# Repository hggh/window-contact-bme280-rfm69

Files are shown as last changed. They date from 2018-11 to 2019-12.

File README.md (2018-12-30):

# window-contact-rfm69

## Parts
 * Atmel 328p
 * RFM69
 * copper foil as contact
 * CR2032 battery

 ## fuse
  * disable BOD
  * internal 1Mhz

the back side of the case. the contacts are made with tiny copper foil.

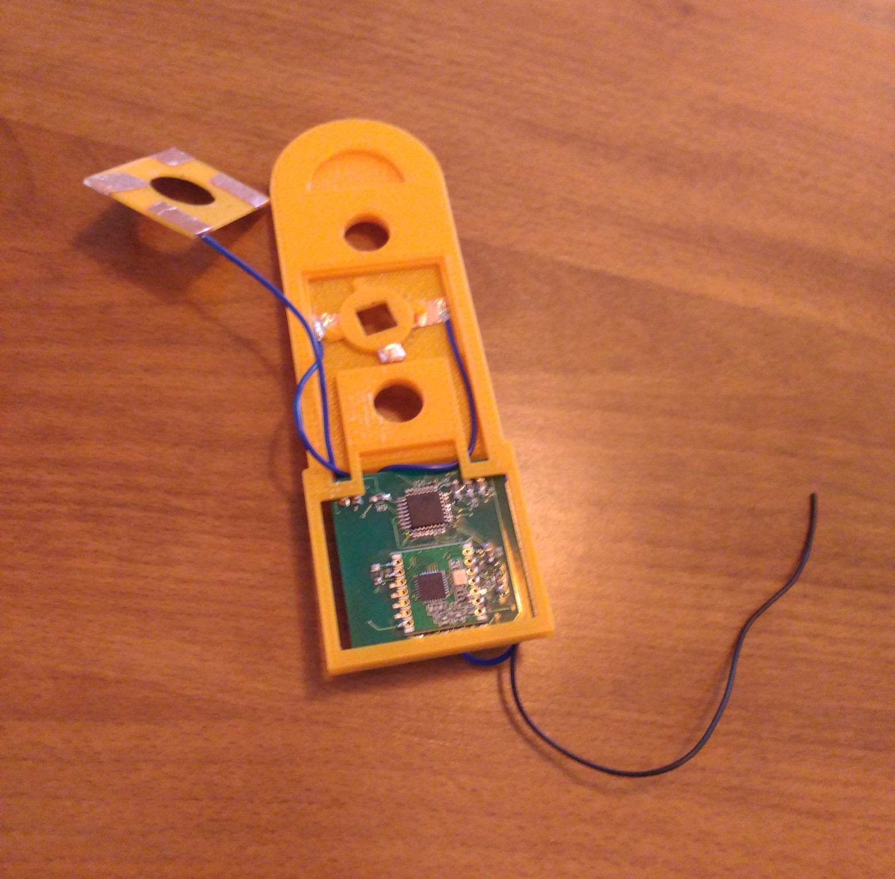
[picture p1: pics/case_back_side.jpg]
case_back


window is half opened and cover is missing to hide the pcb

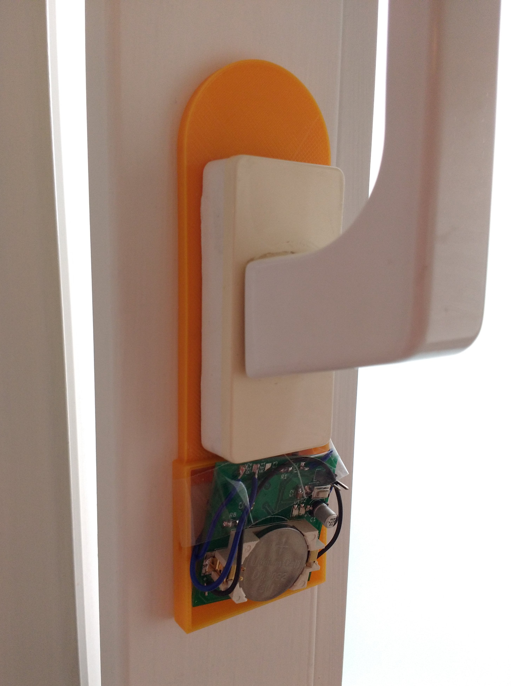
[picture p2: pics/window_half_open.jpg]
window


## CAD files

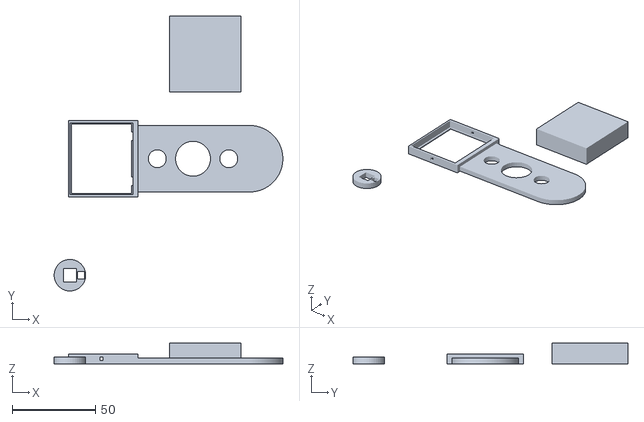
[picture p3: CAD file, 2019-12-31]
case/case-reed-contacts.stl
137.5 x 165.3 x 12.5

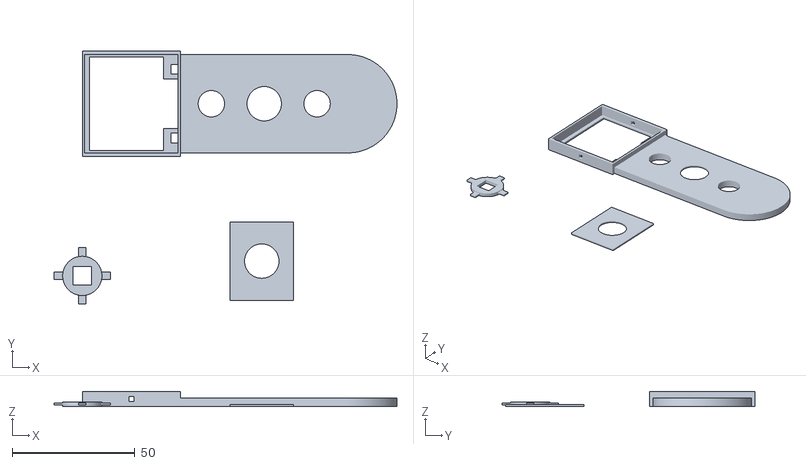
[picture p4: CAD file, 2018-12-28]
case/case.stl
139.5 x 103.0 x 6.00

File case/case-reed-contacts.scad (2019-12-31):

VIERKANT = 7.5;
BREITE = 40;
HOEHE = 68;
BOHRUNGEN = 10.75;

module inlay() {
	difference(){
		cylinder($fn=40, h=4, r=((32/2) - 6.5));
		cube([(VIERKANT + 0.5), (VIERKANT + 0.5), 10], center=true);
		translate([(((32/2)-6)- 3.3), 0, 0]) {
			cube([4, 4.5, 10], center=true);
		}
	}
}

module box() {
    difference() {
        cube([HOEHE, BREITE, 3.5]);
        // Bohrung unten
		translate([(HOEHE - ((HOEHE - 43) / 2)), (BREITE / 2), -1]) {
			cylinder($fn=40 ,h=7, r=(BOHRUNGEN / 2));
		}       
        // Bohrung oben
		translate([((HOEHE - 43) / 2), (BREITE / 2), -1]) {
			cylinder($fn=40, h=6, r=(BOHRUNGEN / 2));
		}
        // Mitte
        translate([((43/2)+((HOEHE-43)/2)),(BREITE/2),-1]) {
			cylinder($fn=40, h=10, r=10.5);
		}
        //Reed Contact
        translate([ (HOEHE-43)/2, (BREITE - 2.2 - 3), -1]) {
            cube([30, 3, 3.3]);
		}
        //Reed Contact
        translate([ (HOEHE-43)/2, 2.2, -1]) {
			cube([30, 3, 3.3]);
		}
    }
}


translate([40, 60, 0]) {
    difference() {
        union() {
            box();
            // Rundung oben
            translate([HOEHE, BREITE / 2, 0]) {
                difference() {
                    cylinder($fn=120, r=BREITE / 2 , h=3.5);
                    translate([-BREITE, - BREITE / 2,-1]) cube([BREITE, BREITE, 10]);
                    translate([0, 0, -1]) cylinder($fn=80, r=BREITE / 2.4 , h=3);
                }
            }
            translate([-41, -3, 0]) {
                difference() {
                    cube([42, 46, 6]);
                    translate([1, 1.5, 1]) {
                        cube([38, 43, 10]);
                    }
                    translate([2, 2, -1]) {
                        cube([36, 42, 5]);
                    }
                    translate([40/2 +1 , -10, 2]) {
                        rotate([0, 0, 90]) cube([60, 2, 2]);
                    }
                }
            }
        }
        translate([-4, 4, -1]) {
            cube([75, 5, 3.7]);
        }
        translate([-4, 31, -1]) {
            cube([75, 5, 3.7]);
        }
    }
    
}


translate([0, 10, 0]) {
    inlay();
}



module deckel() {
    D_BREITE = 40;
    D_HOEHE = 43;
    D_TIEFE = 11;

    union() {
        difference() {
            cube([D_BREITE + 2.8, D_HOEHE  + 2.8,  D_TIEFE + 1.5]);
            translate([1.2, 1.2, 0]) {
                cube([D_BREITE + 0.4, D_HOEHE + 0.4,  D_TIEFE]);
            }
            translate([-1, 1.5 + 1.2, 0]) {
                cube([4, 40 +0.4, 3.5]);
            }
        }
        difference() {
            translate([40/2 + 1.2 +1 , 0, 2]) {
                rotate([0, 0, 90]) cube([D_HOEHE + 2.4,, 2, 2]);
            }
            translate([1.2, 1.2 +2, 0]) {
                cube([D_BREITE, D_HOEHE-4,  D_TIEFE +1]);
            }
        }
    }
}


translate([60, 120, 0 ]) {
    deckel();
}

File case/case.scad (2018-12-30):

VIERKANT = 7.5;
BREITE = 40;
HOEHE = 68;
BOHRUNGEN = 10.75;

module box() {
    difference() {
        cube([HOEHE, BREITE, 3.5]);
        // Bohrung unten
		translate([(HOEHE - ((HOEHE - 43) / 2)), (BREITE / 2), 0]) {
			cylinder($fn=40 ,h=4, r=(BOHRUNGEN / 2));
		}
        
        // Bohrung oben
		translate([((HOEHE - 43) / 2), (BREITE / 2), 0]) {
			cylinder($fn=40, h=4, r=(BOHRUNGEN / 2));
		}
        
        translate([((43/2)+((HOEHE-43)/2)),(BREITE/2),-1]) {
			cylinder($fn=40, h=10, r=7);
		}
        
        translate([((43/2)+((HOEHE-43)/2)) - 12,(BREITE/2) - 15, 0]) {
            cube([24, 30, 2.7]);
        }
        
        translate([((43/2)+((HOEHE-43)/2)) - 13,(BREITE/2) - 16, 0]) {
            cube([26, 32, 0.8]);
        }
    }
}


translate([40, 60, 0]) {
    difference() {
        union() {
            box();
            // Rundung oben
            translate([HOEHE, BREITE / 2, 0]) {
                difference() {
                    cylinder($fn=120, r=BREITE / 2 , h=3.5);
                     translate([-BREITE, - BREITE / 2,0]) cube([BREITE, BREITE, 10]);
                    cylinder($fn=80, r=BREITE / 3.6 , h=1.5);
                }
            }
            translate([-40, -1.5, 0]) {
                difference() {
                    cube([40, 43, 6]);
                    translate([1, 1.5, 1]) {
                        cube([38, 40, 10]);
                    }
                    translate([3, 2.5, 0]) {
                        cube([30, 38, 5]);
                    }
                    translate([40/2 +1 , -10, 2]) {
                        rotate([0, 0, 90]) cube([60, 2, 2]);
                    }
                }
            }
        }
        translate([-4, 4, 0]) {
            cube([26, 4, 2.7]);
        }
        translate([-4, 32, 0]) {
            cube([26, 4, 2.7]);
        }
        translate([-10, BREITE/ 4, 0]) {
            cube([12, 20, 2]);
        }
    }
    
}


translate([60, 0, 0]) {
    difference() {
        cube([26, 32, 0.8]);
        translate([13, 16, 0 ]) {
            cylinder($fn=40, h=10, r=7, center=true);
        }
    }
}


translate([0, 10, 0]) {
    difference(){
        union() {
            cylinder($fn=40, h=1.8, r=8);
            translate([-23 /2, -1.5 , (2 - 0.8) / 2]) {
                cube([23, 3, 0.8]);
            }
            translate([+1.5, - (23 / 2) , (2 - 0.8) / 2]) {
                rotate([0, 0, 90]) cube([23, 3, 0.8]);
            }
        }
        cube([VIERKANT, VIERKANT, 10], center=true);
    }
}



module deckel() {
    D_BREITE = 40;
    D_HOEHE = 43;
    D_TIEFE = 11;

    union() {
        difference() {
            cube([D_BREITE + 2.8, D_HOEHE  + 2.8,  D_TIEFE + 1.5]);
            translate([1.2, 1.2, 0]) {
                cube([D_BREITE + 0.4, D_HOEHE + 0.4,  D_TIEFE]);
            }
            translate([-1, 1.5 + 1.2, 0]) {
                cube([4, 40 +0.4, 3.5]);
            }
        }
        difference() {
            translate([40/2 + 1.2 +1 , 0, 2]) {
                rotate([0, 0, 90]) cube([D_HOEHE + 2.4,, 2, 2]);
            }
            translate([1.2, 1.2 +2, 0]) {
                cube([D_BREITE, D_HOEHE-4,  D_TIEFE +1]);
            }
        }
    }
}


translate([60, 120, 0 ]) {
    deckel();
}

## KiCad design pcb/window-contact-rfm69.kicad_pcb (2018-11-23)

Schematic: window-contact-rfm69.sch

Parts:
BT1: CR2032
C1: 10uF; c_elec_4x5.8
C2, C3: 100nf; C_0805_HandSoldering
D1: RE2; LED_0805
D2: RE1; LED_0805
IC1: ATMEGA328P-A; TQFP-32_7x7mm_Pitch0.8mm
P1: VCC; Wire_SMD_Pad_1PIN
P2: TX/RX; Pin_Header_Straight_1x02
P3: RE1; Wire_SMD_Pad_1PIN
P4: ISP; SMD
P5: RE2; Wire_SMD_Pad_1PIN
P6: AN; Wire_SMD_Pad_1PIN
P7: RE3; Wire_SMD_Pad_1PIN
R1: 10k; R_0805_HandSoldering
R2, R3, R7, R9: 10M; R_0805_HandSoldering
R4, R5, R6: 1k; R_0805_HandSoldering
R8: 100; R_0805_HandSoldering
RF1: RFM69; RFM96
SW1: LED ON; SMD_Button

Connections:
/MISO: IC1.16 ((PCINT4/MISO)PB4), P4.1, R4.2
/MOSI: IC1.15 ((PCINT3/OC2A/MOSI)PB3), P4.4, R6.1
/SCK: IC1.17 ((PCINT5/SCK)PB5), P4.3, R5.1
/SS: IC1.14 ((PCINT2/OC1B/~SS~)PB2), RF1.7 (NSS)
GND: BT1.2 (-), C1.2, C2.2, C3.2, IC1.3 (GND), IC1.5 (GND), IC1.21 (GND), P4.6, R2.2, R3.2, R7.2, R8.1, R9.2, RF1.3 (GND), RF1.14 (GND)
unnamed: D1.1 (K), D2.1 (K), R8.2
unnamed: D1.2 (A), IC1.8 ((PCINT7/XTAL2/TOSC2)PB7)
unnamed: D2.2 (A), IC1.7 ((PCINT6/XTAL1/TOSC1)PB6)
unnamed: IC1.1 ((PCINT19/OC2B/INT1)PD3), R9.1, SW1.1
unnamed: IC1.23 ((PCINT8/ADC0)PC0), P5.1, R3.1
unnamed: IC1.24 ((PCINT9/ADC1)PC1), P3.1, R2.1
unnamed: IC1.25 ((PCINT10/ADC2)PC2), P7.1, R7.1
unnamed: IC1.29 ((PCINT14/~RESET~)PC6), P4.5, R1.2
unnamed: IC1.30 ((PCINT16/RXD)PD0), P2.1
unnamed: IC1.31 ((PCINT17/TXD)PD1), P2.2
unnamed: IC1.32 ((PCINT18/INT0)PD2), RF1.9 (DIO0)
unnamed 28: P6.1, RF1.1 (ANT); also elsewhere on the board
unnamed: R4.1, RF1.8 (MISO)
unnamed: R5.2, RF1.6 (SCK)
unnamed: R6.2, RF1.5 (MOSI)
VCC: BT1.1 (+), C1.1, C2.1, C3.1, IC1.4 (VCC), IC1.6 (VCC), IC1.18 (AVCC), P1.1, P4.2, R1.1, RF1.2 (VCC_3.3V), SW1.2

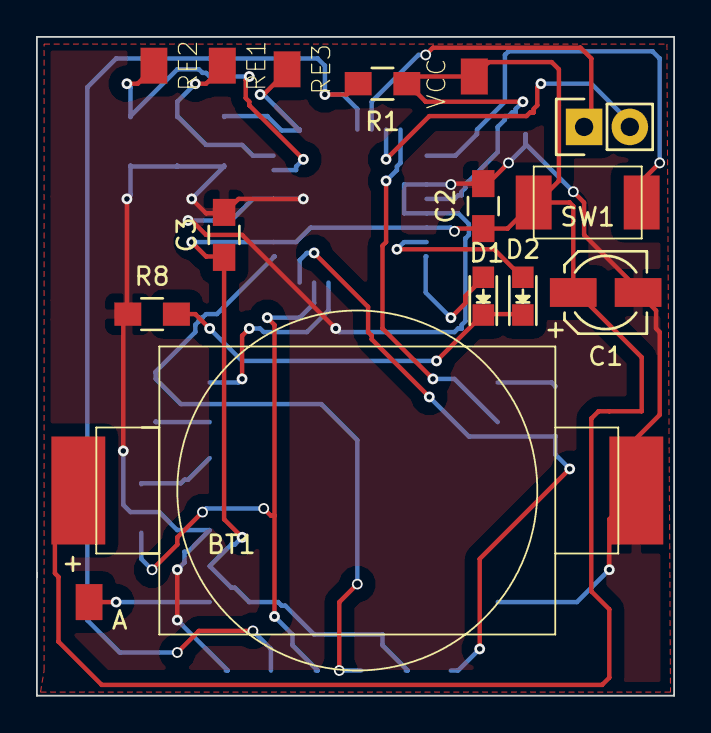
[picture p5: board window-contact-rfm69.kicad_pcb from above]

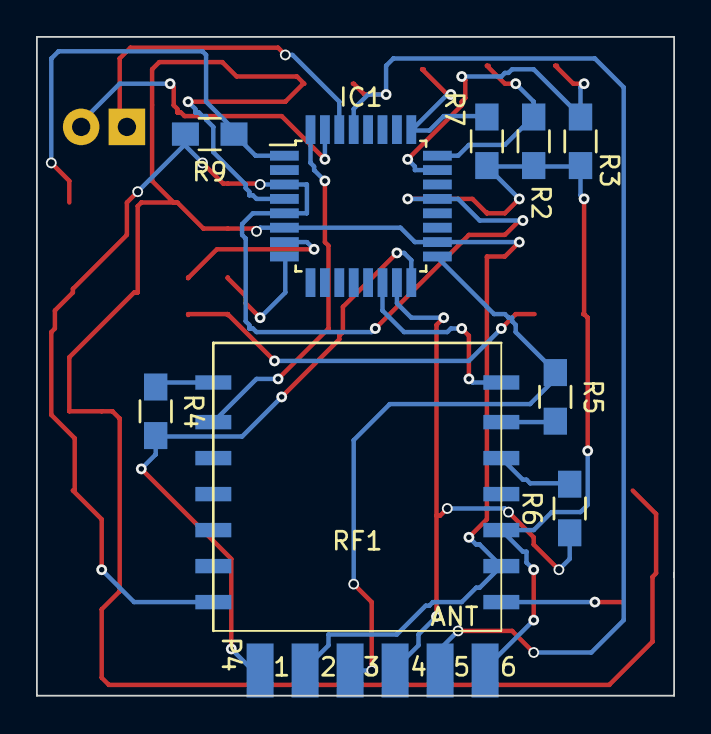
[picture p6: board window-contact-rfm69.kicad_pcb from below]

Board: 2 copper layers, 35.4 x 36.6 mm, 25 parts (10 on the bottom side), 21 nets.

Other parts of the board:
A: AN; Wire_SMD_Pad_1PIN

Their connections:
unnamed 28: A.1; also elsewhere on the board

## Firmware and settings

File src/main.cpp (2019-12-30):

#include "Arduino.h"
#include <avr/power.h>
#include <RFM69.h>
#include <Bounce2.h>
#include <JeeLib.h>
#include <Voltage.h>

#include "config.h"

// push switch
#define PUSH_SWITCH_PIN 3

// reed contact 1 = RE1/P3 = left contact
#define REED_CONTACT_1 A1

// reed contact 2 = RE2/P5 = right contact
#define REED_CONTACT_2 A0

#define WINDOW_STATUS_UNDEFINED 0
#define WINDOW_STATUS_CLOSED    1
#define WINDOW_STATUS_HALF_OPEN 2
#define WINDOW_STATUS_OPENED    3

#define ACTION_STATUS_SLEEP 0
#define ACTION_STATUS_READ 1
#define ACTION_STATUS_AWAKE 2

#define BUTTON_MODE_NO_CONFIGURE 0
#define BUTTON_MODE_CONFIGURE 1

Bounce push_button = Bounce();
RFM69 radio;
Voltage voltage;
volatile short window_status = WINDOW_STATUS_UNDEFINED;
volatile short action_status = ACTION_STATUS_SLEEP;
volatile short button_status = BUTTON_MODE_NO_CONFIGURE;
volatile unsigned long window_weakup_time = 0;

/*
 * arduino does not map the crystal pin to digital pin mapping
 * LEDs are connected to PB6/PB7
 */
void led_d1(uint8_t a) {
  // GREEN LED
  if (a) {
    PORTB |= (1 << PB7);
    return;
  }
  PORTB &= ~(1 << PB7);
}

void led_d2(uint8_t a) {
  // RED LED
  if (a) {
    PORTB |= (1 << PB6);
    return;
  }
  PORTB &= ~(1 << PB6);
}

ISR(WDT_vect) {
  Sleepy::watchdogEvent();
}

ISR(PCINT1_vect) {
  action_status = ACTION_STATUS_READ;
  window_weakup_time = millis();
}

void button_pressed() {
  action_status = ACTION_STATUS_AWAKE;
}

short get_window_status() {
  int reed_status_1 = digitalRead(REED_CONTACT_1);
  int reed_status_2 = digitalRead(REED_CONTACT_2);

#ifdef DEBUG
  Serial.print("Reed Status 1: ");
  Serial.println(reed_status_1);
  Serial.print("Reed Status 2: ");
  Serial.println(reed_status_2);
#endif

  if (WINDOW_ORIENTATION == 1) {
    if (reed_status_1 == LOW and reed_status_2 == HIGH) {
      return WINDOW_STATUS_CLOSED;
    }
    if (reed_status_1 == LOW and reed_status_2 == LOW) {
      return WINDOW_STATUS_OPENED;
    }
    if (reed_status_1 == HIGH and reed_status_2 == LOW) {
      return WINDOW_STATUS_HALF_OPEN;
    }
  }

  if (WINDOW_ORIENTATION == 2) {
    if (reed_status_1 == LOW and reed_status_2 == HIGH) {
      return WINDOW_STATUS_CLOSED;
    }
    if (reed_status_1 == LOW and reed_status_2 == LOW) {
      return WINDOW_STATUS_OPENED;
    }
    if (reed_status_1 == HIGH and reed_status_2 == LOW) {
      return WINDOW_STATUS_HALF_OPEN;
    }
  }
 

  return WINDOW_STATUS_UNDEFINED;
}

void setup_pin_change_interrupt() {
  noInterrupts();
  PCICR |= (1 << PCIE1);

  PCMSK1 |= (1<<PCINT8);
  PCMSK1 |= (1<<PCINT9);

  interrupts();
}

void disable_pin_change_interrupt() {
  noInterrupts();

  PCICR &= ~(1 << PCIE1);
  PCMSK1 &= ~(1<<PCINT8);
  PCMSK1 &= ~(1<<PCINT9);

  interrupts();
}

void send_status(short status) {
  char buffer[30] = "";
  double volt = (double)voltage.read();

  char volt_str[10];
  dtostrf(volt, 3,2, volt_str);

  sprintf(buffer, "%d;WinStatus;%d;%s", NODEID, status, volt_str);

  if (radio.sendWithRetry(GATEWAYID, buffer, strlen(buffer), 4, 120) == false) {
    led_d2(1);
    delay(50);
    led_d2(0);
  }
  else {
    led_d1(1);
    delay(50);
    led_d1(0);
  }
  radio.sleep();

#ifdef DEBUG
  Serial.println(buffer);
  Serial.flush();
#endif
}


void setup() {
#ifdef DEBUG
  Serial.begin(9600);
  Serial.println("Starting window-contact-rfm69");
  Serial.flush();
#else
  power_usart0_disable();
#endif
  power_twi_disable();

  voltage.init();

  pinMode(REED_CONTACT_1, INPUT);
  pinMode(REED_CONTACT_2, INPUT);

  pinMode(PUSH_SWITCH_PIN, INPUT);
  push_button.attach(PUSH_SWITCH_PIN);
  push_button.interval(25);
  attachInterrupt(digitalPinToInterrupt(PUSH_SWITCH_PIN), button_pressed, CHANGE);

  // LED Pins to output
  DDRB |= (1<<PB6);
  DDRB |= (1<<PB7);

  radio.initialize(FREQUENCY, NODEID, NETWORKID);
  radio.encrypt(ENCRYPTKEY);
  radio.sleep();

  window_status = get_window_status();
  send_status(window_status);

  setup_pin_change_interrupt();
}

void loop() {
  push_button.update();

  if (push_button.rose()) {
    noInterrupts();
    if (button_status == BUTTON_MODE_NO_CONFIGURE) {
      // we are in NO CONIFGURE mode, now switch to configuration mode
      button_status = BUTTON_MODE_CONFIGURE;
      disable_pin_change_interrupt();
      led_d1(1);
      _delay_ms(300);
      led_d1(0);
      _delay_ms(600);
      led_d2(1);
      _delay_ms(300);
      led_d2(0);
    }
    else {
      button_status = BUTTON_MODE_NO_CONFIGURE;
      led_d2(1);
      _delay_ms(300);
      led_d2(0);
      _delay_ms(600);
      led_d1(1);
      _delay_ms(300);
      led_d1(0);

      // configure mode is now switched off go back to sleep
      action_status = ACTION_STATUS_SLEEP;
    }
#ifdef DEBUG
    Serial.print("configure mode: ");
    if (button_status == BUTTON_MODE_CONFIGURE) {
      Serial.println("ON");
    }
    else {
      Serial.println("OFF");
    }
    Serial.flush();
#endif
    interrupts();
  }

  if (button_status == BUTTON_MODE_CONFIGURE) {
    // light up LEDs for debugging
    int reed_status_1 = digitalRead(REED_CONTACT_1);
    int reed_status_2 = digitalRead(REED_CONTACT_2);

    // reed contact 1 = RE1/P3 = right contact = RED light
    led_d2(reed_status_1);

    // reed contact 2 = RE2/P5 = left contact = GREEN light
    led_d1(reed_status_2);

  }
  
  if (action_status == ACTION_STATUS_READ) {
    if (millis() > window_weakup_time + 750) {

      window_status = get_window_status();
      send_status(window_status);

      action_status = ACTION_STATUS_SLEEP;
    }
    else {
      Sleepy::loseSomeTime(10);
    }
  }

  
  if (action_status == ACTION_STATUS_SLEEP) {
#ifdef DEBUG
      Serial.println("at action_status == ACTION_STATUS_SLEEP");
      Serial.flush();
#endif
    setup_pin_change_interrupt();
    Sleepy::powerDown();
  }
}

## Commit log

2018-05-20 initial pcb
    [window-contact-bme280-rfm69.kicad_pcb, window-contact-bme280-rfm69.sch]
2018-05-27 PlatformIO Tests with custom board: BOD disabeled, 1Mhz
2018-05-30 only window contact
    [window-contact-bme280-rfm69.kicad_pcb, window-contact-rfm69.kicad_pcb, window-contact-rfm69.sch]
2018-05-30 switched to usbasp
2018-06-03 read battery voltage via internal 1.1V reference
2018-06-03 changed to tqfp atmel
    [window-contact-rfm69.kicad_pcb]
2018-06-10 updated kicad files
    [window-contact-rfm69.kicad_pcb, window-contact-rfm69.sch]
2018-06-10 updated pcb
    [window-contact-rfm69.kicad_pcb]
2018-06-16 changed to ifdef and int; correct disable of PCINT
    [main.cpp]
2018-06-16 added scad file
    [inlay.scad]
2018-08-30 added new case, removed old inlay
    [case2.scad, inlay.scad]
2018-08-30 3 => 3.5mm hoch; more space for reed contacts
    [case2.scad]
2018-08-31 updated case
    [case2.scad]
2018-08-31 renamed, addd stl
    [case.scad, case.stl]
2018-08-31 added Status LEDs and Debug Push Button
    [window-contact-rfm69.sch]
2018-08-31 update to new case and reed contacts
2018-09-06 added 3. reed contact
    [window-contact-rfm69.sch]
2018-11-23 new release of pcb for window four state contact
    [window-contact-rfm69.kicad_pcb, window-contact-rfm69.sch]
2018-11-23 finial version for allpcb
    [window-contact-rfm69.kicad_pcb]
2018-11-23 allpcb order
    [window-contact-rfm69.kicad_pcb]
2018-11-23 added case for pcb
    [case.scad]
2018-11-29 update stl added correct odering of difference
    [case.scad, case.stl]
2018-12-23 wip: buttons leds
2018-12-27 test with no reed contacts
    [case.scad, case.stl]
2018-12-27 updated case: now using contact with copper foil tape
    [case.scad, case.stl]
2018-12-28 added plase to fit lid
    [case.scad, case.stl]
2018-12-28 update case
    [case.scad, case.stl]
2018-12-29 switch to Voltage lib updated logic
2018-12-30 added lid
    [case.scad]
2019-11-19 added new case for reed contact version
    [case-reed-contacts.scad]
2019-12-30 update case for reed contacts
    [case-reed-contacts.scad]
2019-12-31 update reed contact case
    [case-reed-contacts.scad, case-reed-contacts.stl]
